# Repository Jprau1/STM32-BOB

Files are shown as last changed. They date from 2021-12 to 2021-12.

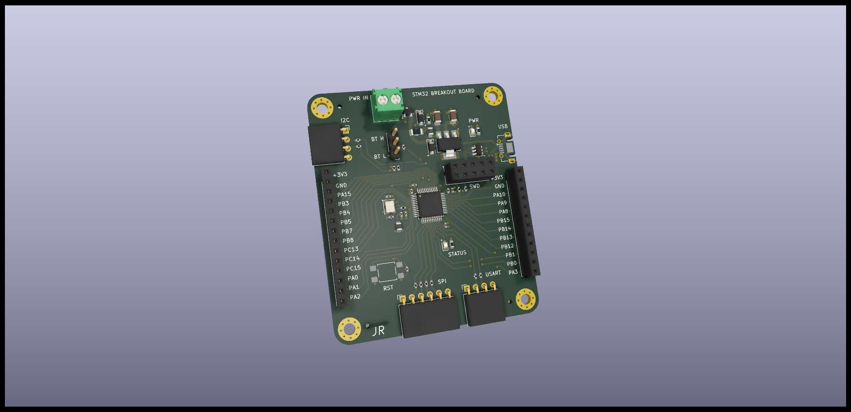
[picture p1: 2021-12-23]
STM32_BOB/STM32_BOB/STM32_BOB.PNG

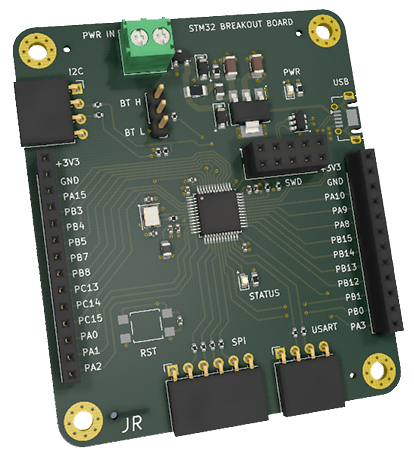
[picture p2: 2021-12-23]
STM32_BOB/STM32_BOB/STM32_ST.png

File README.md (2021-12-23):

# STM32-BOB
This breakout-board project was created in my free time. 
- The MCU used is an STM32F070CBT6
- There are a total of 22 free GPIO ports, along with a +3.3V source and GND port on either side
- The BOB has a dedicated I2C, USART, and SPI port
- Power can be delivered through the Micro USB port or through the screw terminals
- Programs may be flashed through either the Micro USB port or Serial Wire Debug

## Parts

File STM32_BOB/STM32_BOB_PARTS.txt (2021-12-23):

STM32F070CBTx:			https://www.st.com/content/ccc/resource/technical/document/datasheet/31/4f/10/5f/a5/32/46/42/DM00141386.pdf/files/DM00141386.pdf/jcr:content/translations/en.DM001413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
LD1117S33TR: 			https://www.digikey.com/en/products/detail/stmicroelectronics/LD1117S33TR/585766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
(LVR)
AO3401: 			http://www.aosmd.com/pdfs/datasheet/AO3401.pdf
(PMOS)
NX3225GA-16.000M-STD-CRG-1:	https://www.digikey.com/en/products/detail/ndk-america-inc/NX3225GA-16-000M-STD-CRG-1/2261470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
(Crystal)
TFZVTR11B:			https://www.digikey.com/en/products/detail/rohm-semiconductor/TFZVTR11B/5955651
(Zener Diode)
0475900001: 			https://www.digikey.com/en/products/detail/molex/0475900001/1832256
(USB MICRO)
USBLC6-2SC6:			https://www.digikey.com/en/products/detail/stmicroelectronics/USBLC6-2SC6/1040559
(5.25 TVS Diode)
B5819W-TP:			https://www.digikey.com/en/products/detail/micro-commercial-co/B5819W-TP/3774959
(Schottky Diode)
TL3305AF260QG:			https://www.digikey.com/en/products/detail/e-switch/TL3305AF260QG/5816198
(Switch)
0393570002:			https://www.digikey.com/en/products/detail/molex/0393570002/946543
(Screw Terminal)

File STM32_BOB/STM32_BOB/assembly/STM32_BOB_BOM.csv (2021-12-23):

Comment | Designator | Footprint | LCSC
100n | C1 | Capacitor_SMD:C_1206_3216Metric | C24497
12p | C10,C11 | Capacitor_SMD:C_0402_1005Metric | C1547
0.1u | C12 | Capacitor_SMD:C_0402_1005Metric | C1525
10u | C2 | Capacitor_SMD:C_1206_3216Metric | C13585
4.7u | C3 | Capacitor_SMD:C_0402_1005Metric | C23733
100n | C4,C5,C6,C7 | Capacitor_SMD:C_0402_1005Metric | C1525
1u | C8 | Capacitor_SMD:C_0402_1005Metric | C52923
10n | C9 | Capacitor_SMD:C_0402_1005Metric | C15195
11.4Vz | D1 | Diode_SMD:D_SOD-123 | C242274
B5819W | D2 | Diode_SMD:D_SOD-123 | C8598
GRN_LED_2.2V | D3 | LED_SMD:LED_0603_1608Metric | C72043
BLU_LED_3.3V | D4 | LED_SMD:LED_0603_1608Metric | C72041
500mA | F1 | Fuse:Fuse_1206_3216Metric
100 @ 100MHz | FB1,FB2 | Inductor_SMD:L_0805_2012Metric | C1015
MountingHole_Pad | H1,H2,H3,H4 | MountingHole:MountingHole_3mm_Pad_Via
16MHz | HSE1 | Crystal:Crystal_SMD_3225-4Pin_3.2x2.5mm | C13738
Screw_Terminal_01x02 | J1 | TerminalBlock_Phoenix:TerminalBlock_Phoenix_PT-1,5-2-3.5-H_1x02_P3.50mm_Horizontal
USB_B_Micro | J2 | Connector_USB:USB_Micro-AB_Molex_47590-0001
Conn_02x05_Odd_Even | J3 | Connector_PinSocket_2.54mm:PinSocket_2x05_P2.54mm_Vertical
Conn_01x06 | J4 | Connector_PinSocket_2.54mm:PinSocket_1x06_P2.54mm_Horizontal
Conn_01x04 | J5,J6 | Connector_PinSocket_2.54mm:PinSocket_1x04_P2.54mm_Horizontal
Conn_01x12 | J7 | Connector_PinSocket_2.54mm:PinSocket_1x12_P2.54mm_Vertical
Conn_01x14 | J8 | Connector_PinSocket_2.54mm:PinSocket_1x14_P2.54mm_Vertical
Jumper_3_Bridged12 | JP1 | Connector_PinHeader_2.54mm:PinHeader_1x03_P2.54mm_Vertical
AO3401A | Q1 | Package_TO_SOT_SMD:SOT-23 | C15127
330 | R1 | Resistor_SMD:R_0603_1608Metric | C23138
1.5k | R2 | Resistor_SMD:R_0603_1608Metric | C22843
47 | R3 | Resistor_SMD:R_0402_1005Metric | C25118
10k | R4 | Resistor_SMD:R_0402_1005Metric | C25744
2.2k | R5 | Resistor_SMD:R_0603_1608Metric | C4190
4.7k | R6,R7 | Resistor_SMD:R_0402_1005Metric | C25900
22 | R8,R9,R10,R11,R12,R13,R14,R15,R16,R17 | Resistor_SMD:R_0402_1005Metric | C25092
SW_Push | SW1 | Button_Switch_SMD:SW_SPST_TL3305A
LD1117S33TR_SOT223 | U1 | Package_TO_SOT_SMD:SOT-223-3_TabPin2 | C86781
USBLC6-2SC6 | U2 | Package_TO_SOT_SMD:SOT-23-6 | C7519
STM32F070CBTx | U3 | Package_QFP:LQFP-48_7x7mm_P0.5mm | C74909

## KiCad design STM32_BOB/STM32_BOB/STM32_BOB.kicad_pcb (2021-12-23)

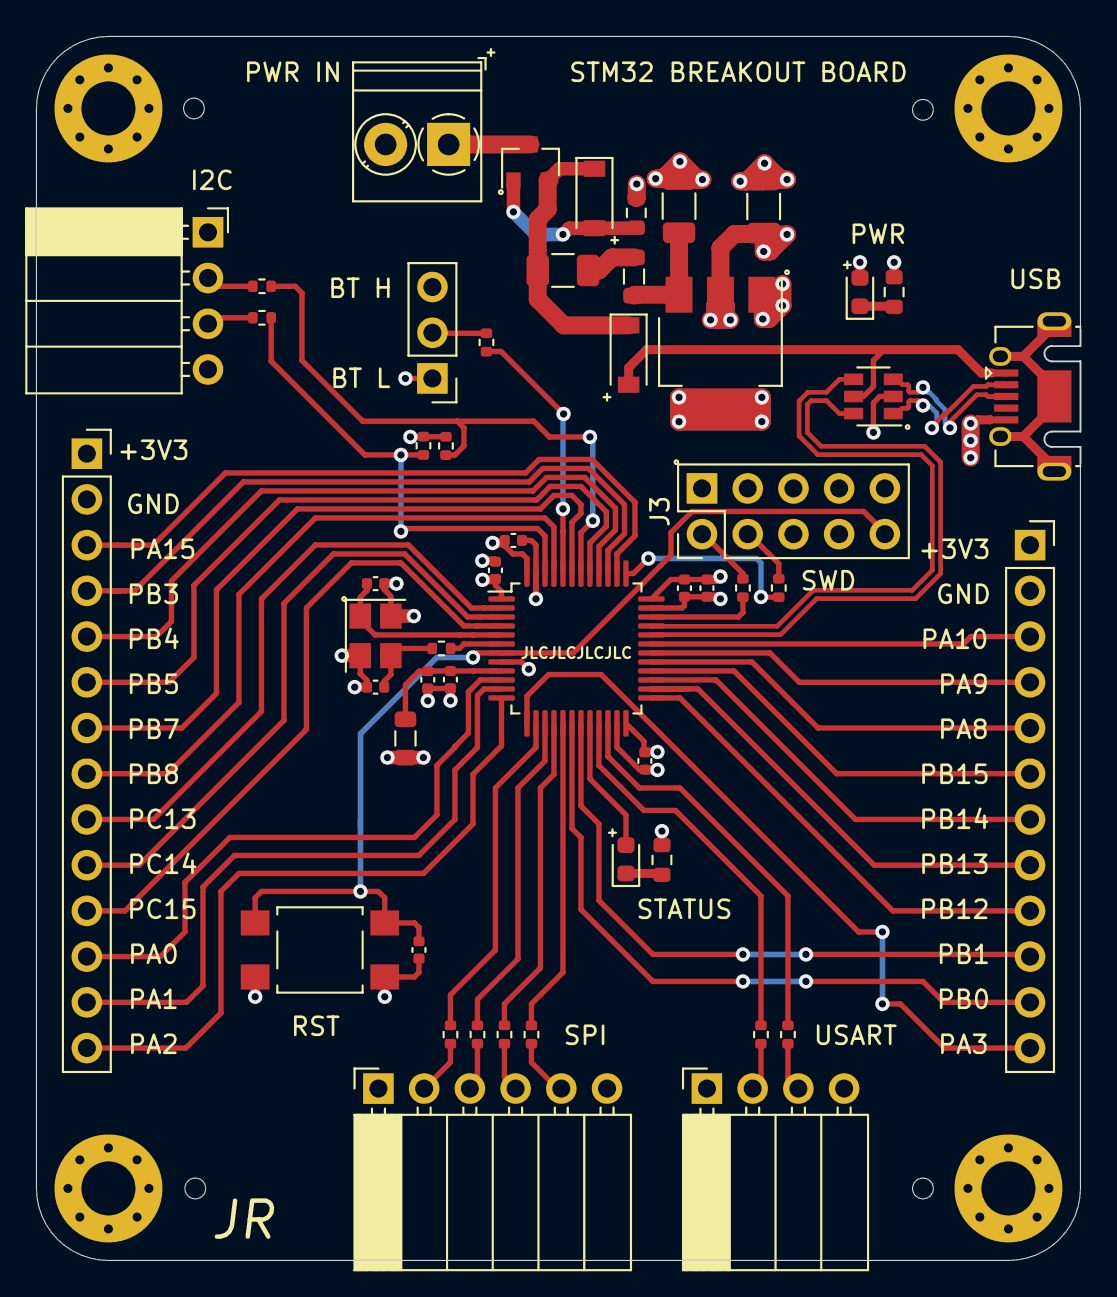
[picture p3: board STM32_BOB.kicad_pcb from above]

Board: 4 copper layers, 58.0 x 68.0 mm, 55 parts (0 on the bottom side), 64 nets.

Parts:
C1: 100n; C_1206_3216Metric
C2: 10u; C_1206_3216Metric
C3: 4.7u; C_0402_1005Metric
C4, C5, C6, C7: 100n; C_0402_1005Metric
C8: 1u; C_0402_1005Metric
C9: 10n; C_0402_1005Metric
C10, C11: 12p; C_0402_1005Metric
C12: 0.1u; C_0402_1005Metric
D1: 11.4Vz; D_SOD-123
D2: B5819W; D_SOD-123
D3: GRN_LED_2.2V; LED_0603_1608Metric
D4: BLU_LED_3.3V; LED_0603_1608Metric
F1: 500mA; Fuse_1206_3216Metric
FB1, FB2: 100 @ 100MHz; L_0805_2012Metric
H1, H2, H3, H4: MountingHole_Pad; MountingHole_3mm_Pad_Via
HSE1: 16MHz; Crystal_SMD_3225-4Pin_3.2x2.5mm
J1: Screw_Terminal_01x02; TerminalBlock_Phoenix_PT-1,5-2-3.5-H_1x02_P3.50mm_Horizontal
J2: USB_B_Micro; USB_Micro-AB_Molex_47590-0001
J3: Conn_02x05_Odd_Even; PinHeader_2x05_P2.54mm_Vertical
J4: Conn_01x06; PinSocket_1x06_P2.54mm_Horizontal
J5, J6: Conn_01x04; PinSocket_1x04_P2.54mm_Horizontal
J7: Conn_01x12; PinSocket_1x12_P2.54mm_Vertical
J8: Conn_01x14; PinSocket_1x14_P2.54mm_Vertical
JP1: Jumper_3_Bridged12; PinHeader_1x03_P2.54mm_Vertical
Q1: AO3401A; SOT-23
R1: 330; R_0603_1608Metric
R2: 1.5k; R_0603_1608Metric
R3: 47; R_0402_1005Metric
R4: 10k; R_0402_1005Metric
R5: 2.2k; R_0603_1608Metric
R6, R7: 4.7k; R_0402_1005Metric
R8, R9, R10, R11, R12, R13, R14, R15, R16, R17: 22; R_0402_1005Metric
SW1: SW_Push; SW_SPST_TL3305A
U1: LD1117S33TR_SOT223; SOT-223-3_TabPin2
U2: USBLC6-2SC6; SOT-23-6
U3: STM32F070CBTx; LQFP-48_7x7mm_P0.5mm

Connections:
+3.3VA: C8.2, C9.2, FB2.1, U3.9
+3V3: C2.2, C3.2, C4.2, C5.2, C6.2, C7.2, D3.2, FB2.2, J3.2, J4.1, J5.1, J6.1, J7.1, J8.1, JP1.3, R6.2, R7.2, U1.2, U3.1, U3.24, U3.36, U3.48
+9V: J1.1, Q1.3
BLU_LED: D4.2, U3.20
BOOT0: R4.1, U3.44
GND: C1.1, C2.1, C3.1, C4.1, C5.1, C6.1, C7.1, C8.1, C9.1, C10.1, C11.1, C12.1, H1.1, H2.1, H3.1, H4.1, HSE1.2, HSE1.4, J1.2, J2.5, J3.4, J3.6, J3.10, J4.6, J5.4, J6.4, J7.2, J8.2, JP1.1, R1.2, R2.2, R5.2, SW1.1, U1.1, U2.2, U3.8, U3.23, U3.35, U3.47
I2C_SCL: R6.1, R14.2, U3.42
I2C_SDA: R7.1, R15.2, U3.46
NRST: C12.2, J3.9, SW1.2, U3.7
unnamed: C1.2, FB1.1, U1.3
unnamed: C11.2, HSE1.3, R3.2
unnamed: D1.1, D2.1, F1.2, Q1.2
unnamed: D1.2, Q1.1, R1.1
unnamed: D3.1, R2.1
unnamed: D4.1, R5.1
unnamed: F1.1, FB1.2
unnamed: J3.1, R8.2
unnamed: J3.3, R9.2
unnamed: J4.2, R10.1
unnamed: J4.3, R11.1
unnamed: J4.4, R12.1
unnamed: J4.5, R13.1
unnamed: J5.2, R14.1
unnamed: J5.3, R15.1
unnamed: J6.2, R16.1
unnamed: J6.3, R17.1
unnamed: JP1.2, R4.2
OSC_IN: C10.2, HSE1.1, U3.5
OSC_OUT: R3.1, U3.6
PA0: J8.12, U3.10
PA1: J8.13, U3.11
PA2: J8.14, U3.12
PA3: J7.12, U3.13
PA8: J7.5, U3.29
PA9: J7.4, U3.30
PA10: J7.3, U3.31
PA15: J8.3, U3.38
PB0: J7.11, U3.18
PB1: J7.10, U3.19
PB3: J8.4, U3.39
PB4: J8.5, U3.40
PB5: J8.6, U3.41
PB7: J8.7, U3.43
PB8: J8.8, U3.45
PB12: J7.9, U3.25
PB13: J7.8, U3.26
PB14: J7.7, U3.27
PB15: J7.6, U3.28
PC13: J8.9, U3.2
PC14: J8.10, U3.3
PC15: J8.11, U3.4
PORT_USB_D+: J2.3, U2.3
PORT_USB_D-: J2.2, U2.1
SPI1_MISO: R12.2, U3.16
SPI1_MOSI: R13.2, U3.17
SPI1_NSS: R10.2, U3.14
SPI1_SCK: R11.2, U3.15
SWCLK: R9.1, U3.37
SWDIO: R8.1, U3.34
USART3_RX: R17.2, U3.22
USART3_TX: R16.2, U3.21
USB_D+: U2.4, U3.33
USB_D-: U2.6, U3.32
VCC: D2.2, J2.1, U2.5
